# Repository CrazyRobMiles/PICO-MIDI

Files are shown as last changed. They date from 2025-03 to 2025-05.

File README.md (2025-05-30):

# PICO-MIDI
Some notes on getting started with MIDI on a PICO using a M5Stack devices [MIDI](https://docs.m5stack.com/en/unit/Unit-MIDI) and [Synth](https://docs.m5stack.com/en/unit/Unit-Synth) to accompany an article in [Raspberry Pi Official Magazine issue 154](https://magazine.raspberrypi.com/issues/154). 
 
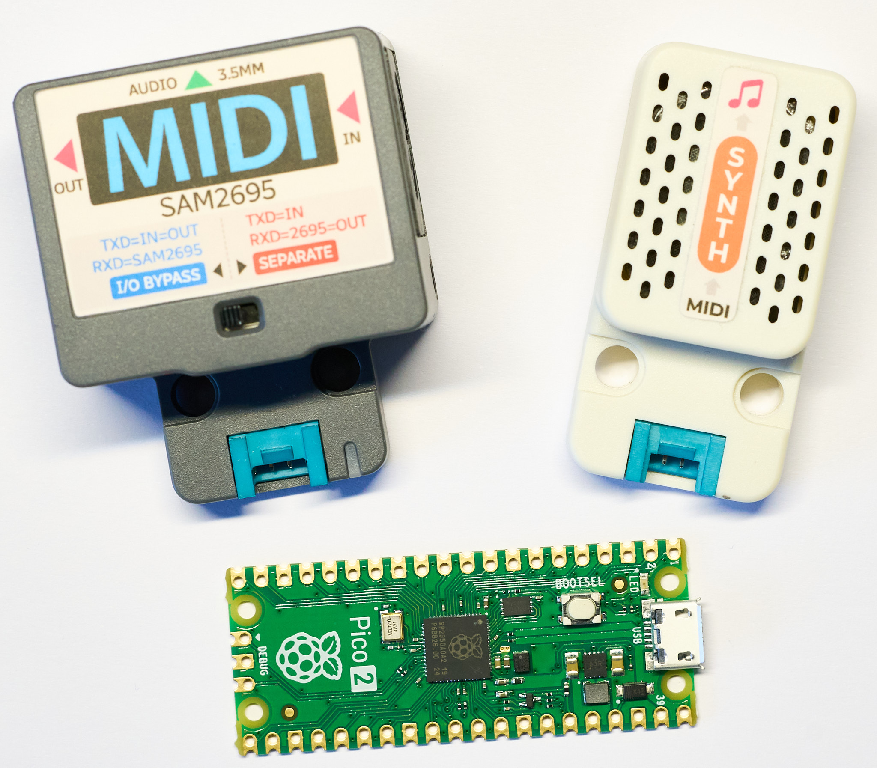
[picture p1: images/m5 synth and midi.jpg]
M5 Stack MIDI devices

These notes have been written for the Raspberry Pi PICO family. The code might need slight modification to run on other devices supporting Circuit Python.  

# PICO MusicBox

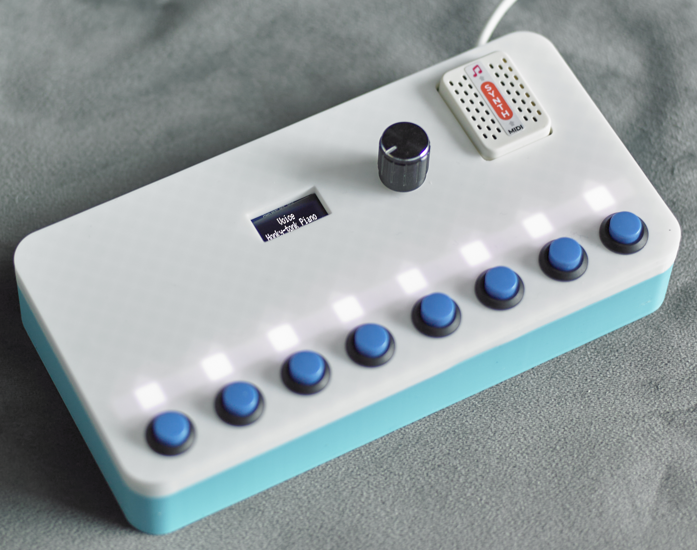
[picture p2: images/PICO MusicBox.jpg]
PICO MusicBox device
 
The PICO MusicBox is powered by Synth device and a PICO. It has an eight button keyboard, a rotary encoder for selecting options and a small OLED panel. It also has coloured leds for each note. You can find the case design in the case folder in this repository. Control software for the MusicBox is in the python folder. Copy all the library files, the font file and code.py onto your Circuit Python device to get it going. 

## Software Installation
The music box is powered by a Circuit Python program. Follow the instructions [here](https://learn.adafruit.com/welcome-to-circuitpython/installing-circuitpython) to install version 9 on your PICO. That's the one for which the pre-built image will work). Then plug your PICO into your computer. An external drive will open up. Copy the entire contents of the python folder onto the root of this drive. Now unplug your PICO and plug it back in again. The external drive will no longer appear on your computer and your PICO will be running the music software.

## MusicBox Commands

* Press any key to make a note, starting at middle C in the major scale
* Turn the encoder to select options
* Press the encoder in to select the option that you are currently adjusting
* Hold the encoder down for two seconds to switch between "drum" and "keyboard" modes. In drum mode the key lights are blue, in keyboard mode the key lights are grey.

# Sample Code

The samples folder contains small sample programs:

* **01SingleNote** - plays a single note
* **O2SimpleTune** - plays a simple tune
* **03SingleNote** - implements key behaviour for a single note
* **04Keyboard** - implements an eight key keyboard
* **05Voices** - shows how different voices are selected
* **06Control** - sends control messages to change the sound output
* **07Drums** - shows how drums are played 

# Hardware connections

## Minimal synth
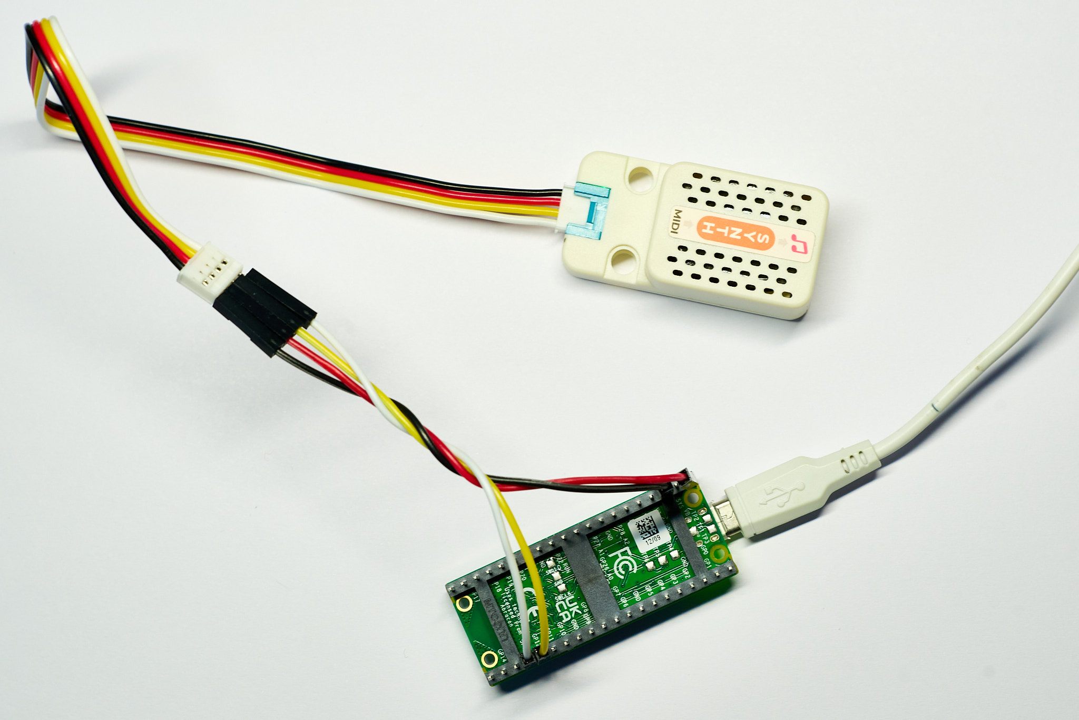
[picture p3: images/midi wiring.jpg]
M5 Stack synth and PICO


You can make a minimal sound device  by connecting the PICO to one of the MIDI devices. The synth is powered from the VSYS 5-volt output from the PICO and connected to GPIO12 and GPIO13 for serial communication. If you use different pins you will have to modify the example code here.

## PICO MusicBox

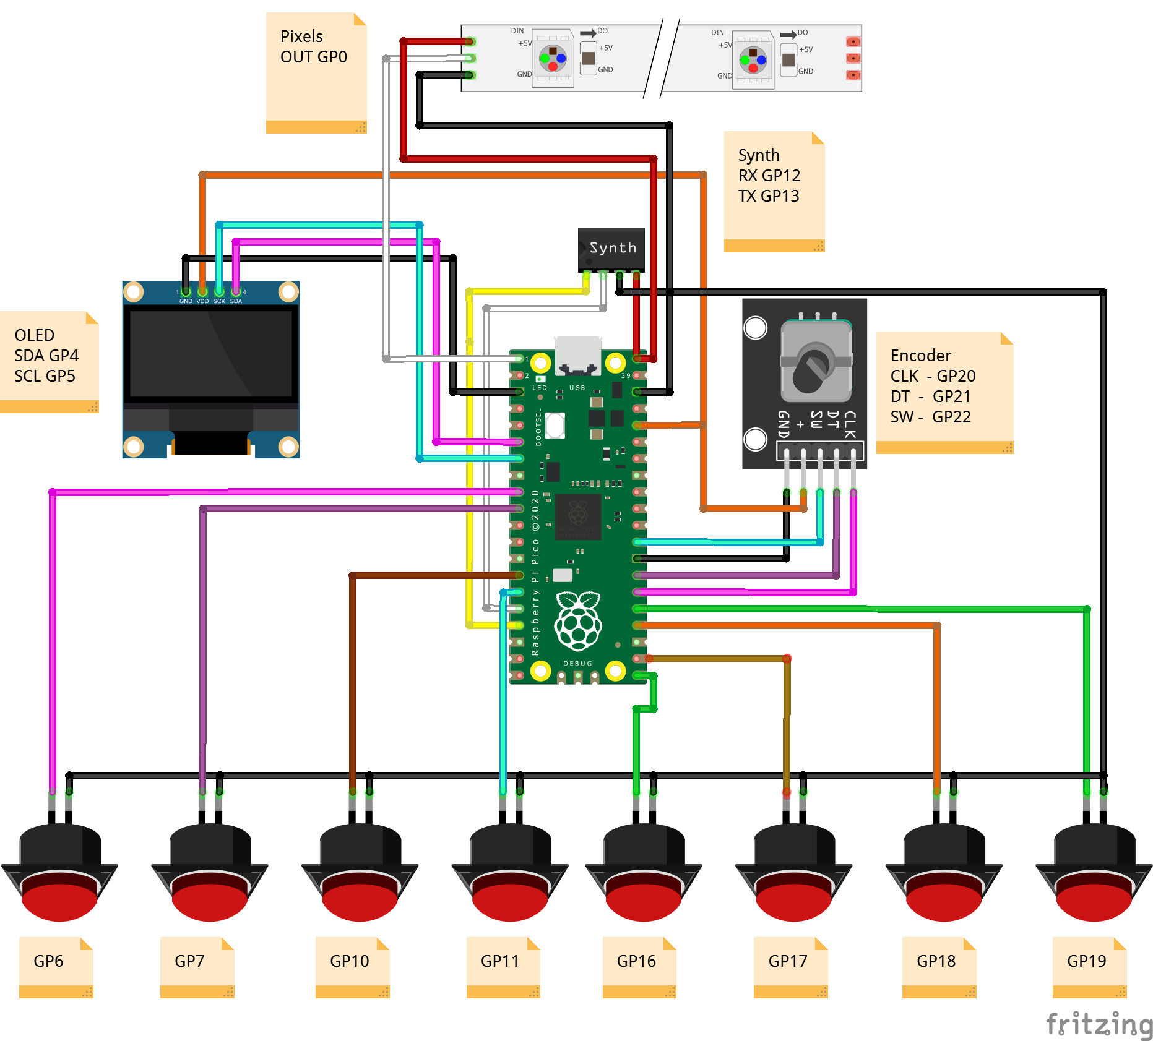
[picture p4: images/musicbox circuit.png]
PICO keyboard circuit


This is the circuit for the complete music box. The code below maps the hardware below onto the software. If you use different connections you will need to change this.

```
notes = [(board.GP6,60,ACOUSTIC_BASS_DRUM),
         (board.GP7,62,ACOUSTIC_SNARE),
         (board.GP10,64,CLOSED_HIHAT),
         (board.GP11,65,OPEN_HIHAT),
         (board.GP16,67,CRASH_CYMBAL_1),
         (board.GP17,69,RIDE_CYMBAL_1),
         (board.GP18,71,LOW_TOM),
         (board.GP19,72,LOW_FLOOR_TOM)]

box = MusicBox(notes,
               board.GP12, board.GP13, #midi
               board.GP21,board.GP20,board.GP22, # rotary
               board.GP5, board.GP4, #display
               board.GP0) #pixel
```

# MIDI on CircuitPython
To send MIDI commands from a CircuitPython program we use the [AdaFruit MIDI library](https://docs.circuitpython.org/projects/midi/en/latest/api.html). The Python folder in this repository contains a lib folder which contains the required library files for Circuit Python version 9. Copy this folder onto your Circuit Python device. If you want to use a different version of Circuit Python on your device you can find the library bundles [here](https://docs.circuitpython.org/projects/bundle/en/latest/).

The resources you need are these:

* **adafruit_midi** folder for the MIDI class
* **adafruit_bus_device** folder for the serial port drivers 
* **Debouncer** for the input signal debouncer

# Case

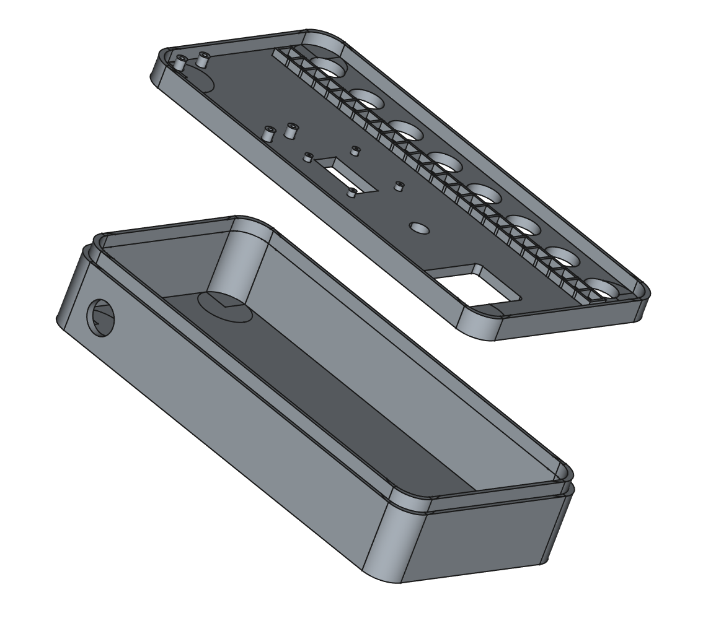
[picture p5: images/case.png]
Case designs in FreeCAD


You can find designs for the case in the case folder. It seemed logical to put them there. I used a flexible led strip. The current software only lights up some of the leds. Use tape or hot glue to hold the sound module in place. I stuck a battery holder into the base and added a switch to make a portable instrument. Alternatively you can just run a usb cable through the switch hole. 

Have Fun

You can find more of my projects [here](https://www.robmiles.com/projects)

Rob Miles

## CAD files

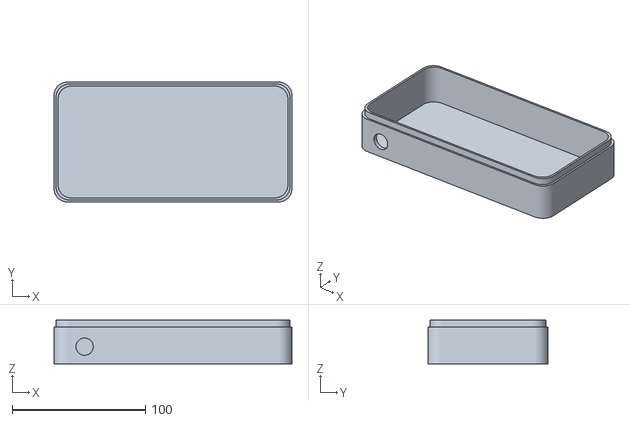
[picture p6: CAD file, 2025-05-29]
case/base.stl
178.7 x 90.0 x 33.0

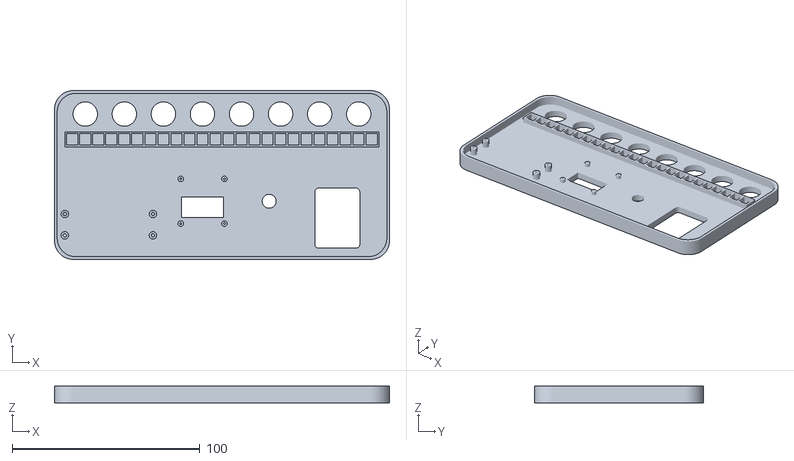
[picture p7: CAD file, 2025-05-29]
case/top.stl
178.7 x 90.0 x 9.00

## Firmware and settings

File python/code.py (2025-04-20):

#Example 4: Complete keyboard

version="Version 1.0"

import time
import usb_midi
import adafruit_midi
from adafruit_midi.note_on import NoteOn
from adafruit_midi.note_off import NoteOff
from adafruit_midi.program_change import ProgramChange
from adafruit_midi.control_change import ControlChange

import busio as io
import board
from digitalio import DigitalInOut, Pull
from adafruit_debouncer import Debouncer
import adafruit_ssd1306
import rotaryio
import neopixel

class Col:
    
    RED = (255, 0, 0)
    YELLOW = (255, 150, 0)
    GREEN = (0, 255, 0)
    CYAN = (0, 255, 255)
    BLUE = (0, 0, 255)
    MAGENTA = (255, 0, 255)
    WHITE = (255, 255, 255)
    BLACK = (0, 0, 0)
    GREY = (10, 10, 10)
    VIOLET = (127,0,155)
    INDIGO = (75,0,130)
    ORANGE = (255,165,0)

    values=(RED, GREEN, BLUE, YELLOW, MAGENTA, CYAN, GREY, WHITE)
     
    @staticmethod
    def dim(col):
        return (col[0]/40, col[1]/40, col[2]/40)
    
MUSIC_STATE = 0
DRUMS_STATE = 1

NO_OF_STATES = 2

state_number = 0

class Key():
    def __init__(self, pin, midi_note, drum_note,pixel):
        self.pin = pin
        tmp_pin = DigitalInOut(pin)
        tmp_pin.pull = Pull.UP
        self.debouncer = Debouncer(tmp_pin,interval=0.01)
        self.midi_note = midi_note
        self.drum_note = drum_note
        self.pixel = pixel
        self.note_playing = False
        
    def play_note(self):
        midi.send(NoteOn(self.midi_note, 100))
        self.note_playing = True
        pixels[self.pixel]=Col.RED
        
    def clear_note(self):
        if self.note_playing:
            midi.send(NoteOff(self.midi_note, 100))
            self.note_playing = False
        pixels[self.pixel]=Col.GREY
        
    def clear_drum(self):
        pixels[self.pixel]=Col.BLUE
        
    def play_drum(self):
        midi.send(NoteOn(self.drum_note, 100),channel=9)
        pixels[self.pixel]=Col.CYAN
        
    def clear(self):
        if state_number == 0:
            self.clear_note()
        elif state_number == 1:
            self.clear_drum()
        
    def play(self):
        if state_number == 0:
            self.play_note()
        elif state_number == 1:
            self.play_drum()
        
    def update(self):
        self.debouncer.update()
        
        if self.debouncer.fell:
            self.play()
                
        if self.debouncer.rose:
            self.clear()
            
class Display():
    
    WIDTH=128
    HEIGHT=32

    def __init__(self,sda,scl,orientation=1):
        print("Display starting")
        self.i2c = io.I2C(sda, scl)
        self.oled = adafruit_ssd1306.SSD1306_I2C(Display.WIDTH, Display.HEIGHT, self.i2c)
        if orientation==1:
            self.oled.rotation = 2
        else:
            self.oled.rotation = 0
        self.topline=""
        self.midline=""
        self.baseline=""
        self.old_topline=""
        self.old_midline=""
        self.old_baseline=""
        self.oled.fill(0)

    def place_text(self,text,y,size):
        x = int((Display.WIDTH-(len(text)*6*size))/2)
        self.oled.text(text,x,y,1,size=size)
        
    def render(self):
        oled = self.oled
        oled.fill(0)
        self.place_text(self.topline,0,1)
        self.place_text(self.midline,9,1)
        self.place_text(self.baseline,25,1)
        self.oled.show()
        
    def update(self):
        if self.topline==self.old_topline and self.midline==self.old_midline and self.baseline==self.old_baseline:
            return
        self.render()
        self.old_topline = self.topline
        self.old_midline = self.midline
        self.old_baseline = self.baseline
        
midi_instruments = [
    ("Acoustic Grand Piano", 0),
    ("Bright Acoustic Piano", 1),
    ("Electric Grand Piano", 2),
    ("Honky-tonk Piano", 3),
    ("Electric Piano 1", 4),
    ("Electric Piano 2", 5),
    ("Harpsichord", 6),
    ("Clavinet", 7),
    ("Celesta", 8),
    ("Glockenspiel", 9),
    ("Music Box", 10),
    ("Vibraphone", 11),
    ("Marimba", 12),
    ("Xylophone", 13),
    ("Tubular Bells", 14),
    ("Dulcimer", 15),
    ("Drawbar Organ", 16),
    ("Percussive Organ", 17),
    ("Rock Organ", 18),
    ("Church Organ", 19),
    ("Reed Organ", 20),
    ("Accordion", 21),
    ("Harmonica", 22),
    ("Tango Accordion", 23),
    ("Acoustic Guitar (nylon)", 24),
    ("Acoustic Guitar (steel)", 25),
    ("Electric Guitar (jazz)", 26),
    ("Electric Guitar (clean)", 27),
    ("Electric Guitar (muted)", 28),
    ("Overdriven Guitar", 29),
    ("Distortion Guitar", 30),
    ("Guitar Harmonics", 31),
    ("Acoustic Bass", 32),
    ("Electric Bass (finger)", 33),
    ("Electric Bass (pick)", 34),
    ("Fretless Bass", 35),
    ("Slap Bass 1", 36),
    ("Slap Bass 2", 37),
    ("Synth Bass 1", 38),
    ("Synth Bass 2", 39),
    ("Violin", 40),
    ("Viola", 41),
    ("Cello", 42),
    ("Contrabass", 43),
    ("Tremolo Strings", 44),
    ("Pizzicato Strings", 45),
    ("Orchestral Harp", 46),
    ("Timpani", 47),
    ("String Ensemble 1", 48),
    ("String Ensemble 2", 49),
    ("Synth Strings 1", 50),
    ("Synth Strings 2", 51),
    ("Choir Aahs", 52),
    ("Voice Oohs", 53),
    ("Synth Choir", 54),
    ("Orchestra Hit", 55),
    ("Trumpet", 56),
    ("Trombone", 57),
    ("Tuba", 58),
    ("Muted Trumpet", 59),
    ("French Horn", 60),
    ("Brass Section", 61),
    ("Synth Brass 1", 62),
    ("Synth Brass 2", 63),
    ("Soprano Sax", 64),
    ("Alto Sax", 65),
    ("Tenor Sax", 66),
    ("Baritone Sax", 67),
    ("Oboe", 68),
    ("English Horn", 69),
    ("Bassoon", 70),
    ("Clarinet", 71),
    ("Piccolo", 72),
    ("Flute", 73),
    ("Recorder", 74),
    ("Pan Flute", 75),
    ("Blown Bottle", 76),
    ("Shakuhachi", 77),
    ("Whistle", 78),
    ("Ocarina", 79),
    ("Lead 1 (square)", 80),
    ("Lead 2 (sawtooth)", 81),
    ("Lead 3 (calliope)", 82),
    ("Lead 4 (chiff)", 83),
    ("Lead 5 (charang)", 84),
    ("Lead 6 (voice)", 85),
    ("Lead 7 (fifths)", 86),
    ("Lead 8 (bass+lead)", 87),
    ("Pad 1 (new age)", 88),
    ("Pad 2 (warm)", 89),
    ("Pad 3 (polysynth)", 90),
    ("Pad 4 (choir)", 91),
    ("Pad 5 (bowed)", 92),
    ("Pad 6 (metallic)", 93),
    ("Pad 7 (halo)", 94),
    ("Pad 8 (sweep)", 95),
    ("FX 1 (rain)", 96),
    ("FX 2 (soundtrack)", 97),
    ("FX 3 (crystal)", 98),
    ("FX 4 (atmosphere)", 99),
    ("FX 5 (brightness)", 100),
    ("FX 6 (goblins)", 101),
    ("FX 7 (echoes)", 102),
    ("FX 8 (sci-fi)", 103),
    ("Sitar", 104),
    ("Banjo", 105),
    ("Shamisen", 106),
    ("Koto", 107),
    ("Kalimba", 108),
    ("Bagpipe", 109),
    ("Fiddle", 110),
    ("Shanai", 111),
    ("Tinkle Bell", 112),
    ("Agogo", 113),
    ("Steel Drums", 114),
    ("Woodblock", 115),
    ("Taiko Drum", 116),
    ("Melodic Tom", 117),
    ("Synth Drum", 118),
    ("Reverse Cymbal", 119),
    ("Guitar Fret Noise", 120),
    ("Breath Noise", 121),
    ("Seashore", 122),
    ("Bird Tweet", 123),
    ("Telephone Ring", 124),
    ("Helicopter", 125),
    ("Applause", 126),
    ("Gunshot", 127),
]

class VoiceSetting:
    
    def __init__(self):
        self.name = "Voice"
        self.set(0)
        
    def update(self,change):
        
        if change==0:
            return
        
        new_voice = self.voice + change
        
        if new_voice<0:
            new_voice=0
        
        if new_voice > len(midi_instruments):
            new_voice = len(midi_instruments)
            
        if new_voice == self.voice:
            return
        
        self.set(new_voice)
        
    def set(self,voice):
        if voice<0 or voice>=len(midi_instruments):
            return
        
        self.voice = voice
        (voice_name,number)=midi_instruments[voice]
        midi.send(ProgramChange(number))
        
    def show(self):
        display.topline=self.name
        (voice_name,number)=midi_instruments[self.voice]
        display.midline=voice_name

class ControlSetting:
    
    def __init__(self,name, message_number,initial_value=0):
        self.name = name
        self.message_number = message_number
        self.set(initial_value)
        
    def update(self,change):
        
        if change==0:
            return
        
        new_level = self.level + change
        
        if new_level<0:
            new_level=0
        
        if new_level > 127:
            new_voice = 127
            
        if new_level == self.level:
            return
        
        self.set(new_level)
        

    def set(self,level):
        if level<0 or level>127:
            return
        self.level=level
        midi.send(ControlChange(self.message_number, level))
        
    def show(self):
        display.topline=self.name
        display.midline=str(self.level)

class MusicBox():
    
    def __init__(self,
                 notes,
                 midi_tx, midi_rx,
                 encoder_a,encoder_b,encoder_button,
                 display_sda,display_scl,
                 pixel_pin, orientation=0):
        global midi
        global display
        global pixels
        pixels_per_note=3
        pixel = 1
        voice=0
        # Create keys
        keyboard = []
        for note in notes:
            (pin,midi_note,drum_note)=note
            keyboard.append(Key(pin,midi_note,drum_note,pixel))
            pixel=pixel=pixel+pixels_per_note

        self.keyboard = keyboard
        # Make encoder
        self.encoder= rotaryio.IncrementalEncoder(encoder_a, encoder_b)
        self.old_encoder_pos = self.encoder.position
        # Make encoder button
        tmp_pin = DigitalInOut(encoder_button)
        tmp_pin.pull = Pull.UP
        self.encoder_button = Debouncer(tmp_pin,interval=0.01)
        self.encoder_pressed = False
        display = Display(display_sda,display_scl,orientation)
        display.topline="Music Box"
        display.midline="Rob Miles"
        display.baseline=version
        display.update()
        time.sleep(1)
        pixels_per_note = 3
        pixel_length = len(notes)*pixels_per_note
        pixels = neopixel.NeoPixel(pixel_pin,pixel_length,auto_write=False)
        
        for key in keyboard:
            pixels[key.pixel] = Col.GREY

        pixels.show()

        if midi_tx != None:
            uart = io.UART(board.GP12, board.GP13, baudrate=31250)
            midi = adafruit_midi.MIDI(midi_out=uart, out_channel=0)
        else:
            midi = adafruit_midi.MIDI(midi_out=usb_midi.ports[1], out_channel=0)
            
        self.settings = [ VoiceSetting(), ControlSetting("Reverb",91), ControlSetting("Chorus",93), ControlSetting("Vibrato",1), ControlSetting("Portmanto",5) ]
        self.select_setting(0)
        
    def next_setting(self):
        new_setting = self.setting_number + 1
        if new_setting >= len(self.settings):
            new_setting=0
        self.select_setting(new_setting)
            
    def select_setting(self,number):
        if number<0 or number>=len(self.settings):
            return
        
        self.setting_number = number
        setting = self.settings[number]
        setting.show()
        
    def encoder_update(self):
        global state_number
        self.encoder_button.update()
        if self.encoder_button.fell:
            self.next_setting()
            self.encoder_down_time = time.monotonic()
            self.encoder_pressed=True
        if self.encoder_button.rose:
            self.encoder_pressed=False
        
        if self.encoder_pressed:
            
            current_time = time.monotonic()
            
            if current_time-self.encoder_down_time > 2.0:

                state_number = state_number + 1
                
                if state_number >= NO_OF_STATES:
                    state_number = 0
                    
                for key in self.keyboard:
                    key.clear()
                    
                self.encoder_down_time = current_time
        
        new_encoder_pos = self.encoder.position
        
        if new_encoder_pos == self.old_encoder_pos:
            return

        change = self.old_encoder_pos-new_encoder_pos
        
        self.old_encoder_pos=new_encoder_pos
        setting = self.settings[self.setting_number]
        setting.update(change)
        setting.show()
        
    def update(self):
        for key in self.keyboard:
            key.update()
        self.encoder_update()
        display.update()
        pixels.show()
    
ACOUSTIC_BASS_DRUM = 35
ACOUSTIC_SNARE = 38
CLOSED_HIHAT = 42
OPEN_HIHAT = 46
CRASH_CYMBAL_1 = 49
RIDE_CYMBAL_1 = 51
LOW_TOM = 45
LOW_FLOOR_TOM = 41

notes = [(board.GP6,60,ACOUSTIC_BASS_DRUM),
         (board.GP7,62,ACOUSTIC_SNARE),
         (board.GP10,64,CLOSED_HIHAT),
         (board.GP11,65,OPEN_HIHAT),
         (board.GP16,67,CRASH_CYMBAL_1),
         (board.GP17,69,RIDE_CYMBAL_1),
         (board.GP18,71,LOW_TOM),
         (board.GP19,72,LOW_FLOOR_TOM)]

box = MusicBox(notes,
               board.GP12, board.GP13, #midi
               board.GP21,board.GP20,board.GP22, # rotary
               board.GP5, board.GP4, #display
               board.GP0) #pixel

while True:
    box.update()

    

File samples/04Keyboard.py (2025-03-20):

#Example 4: Complete keyboard

import time
import usb_midi
import adafruit_midi
from adafruit_midi.note_on import NoteOn
from adafruit_midi.note_off import NoteOff
import busio as io
import board
from digitalio import DigitalInOut, Pull
from adafruit_debouncer import Debouncer


## Drive synth from the serial port
## comment out these lines for usb use
uart = io.UART(board.GP12, board.GP13, baudrate=31250)
midi = adafruit_midi.MIDI(midi_out=uart, out_channel=0)

## Drive a synth from the USB port
## comment out this line for serial use
# midi = adafruit_midi.MIDI(midi_out=usb_midi.ports[1], out_channel=0)

class Key():
    def __init__(self, pin, midi_note):
        self.pin = pin
        tmp_pin = DigitalInOut(pin)
        tmp_pin.pull = Pull.UP
        self.debouncer = Debouncer(tmp_pin,interval=0.01)
        self.midi_note = midi_note
        
    def update(self):
        self.debouncer.update()
        if self.debouncer.fell:
            midi.send(NoteOn(self.midi_note, 100))
        if self.debouncer.rose:
            midi.send(NoteOff(self.midi_note, 100))
            
note_descriptions = [(board.GP6,60),(board.GP7,62),(board.GP10,64),
         (board.GP11,65),(board.GP16,67),(board.GP17,69),
         (board.GP18,71),(board.GP19,72)]

keyboard = []

for note in note_descriptions:
    (pin,midi_note)=note
    keyboard.append(Key(pin,midi_note))

while True:
    for key in keyboard:
        key.update()

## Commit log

2025-03-20 Final version, minus case files
2025-05-29 Added case designs
    [base.stl, top.stl]
